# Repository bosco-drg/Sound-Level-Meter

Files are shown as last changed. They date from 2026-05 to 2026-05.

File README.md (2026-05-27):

# Sonomètre — Projet de mesure de niveau sonore

> Projet complet de sonomètre électronique : schéma, PCB (KiCad) et simulations (LTSpice).

---

## Aperçu rapide

Ce dépôt contient la conception d'un **sonomètre** (instrument de mesure du niveau sonore) couvrant l'adaptation d'entrée, la conditionnement du signal, le filtrage, la détection RMS/Crête, l'acquisition et les aspects matériels (schéma et PCB). Sont inclus : le **schéma**, le **PCB** et les **simulations**.

### Points clés

- **Mesure de niveau sonore** : détection RMS et/ou crête, calcul de niveaux (dB SPL)
- **Pondérations et filtres** : options de filtrage (pondération A/B) pour mesures conforme
- **Calibration** : procédures et composants pour calibration avec source connue
- **Conception matérielle** : schéma et routage PCB sous KiCad
- **Simulations** : modèles LTSpice pour valider le conditionnement et la détection
- **Documentation visuelle** : diagrammes fonctionnels et captures de simulation

---

## PCB

<div align="center">

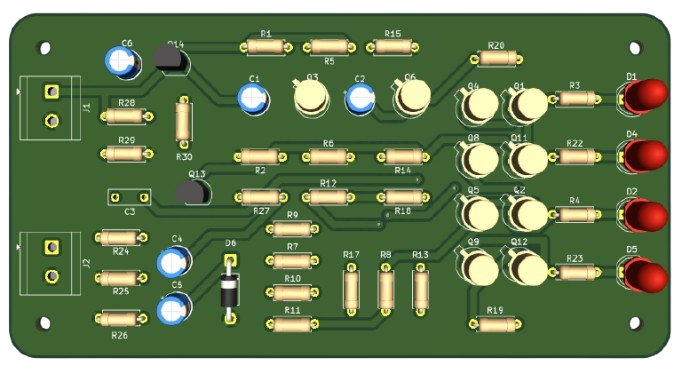
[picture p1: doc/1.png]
PCB back side


**PCB — côté composants**

</div>

<div align="center">

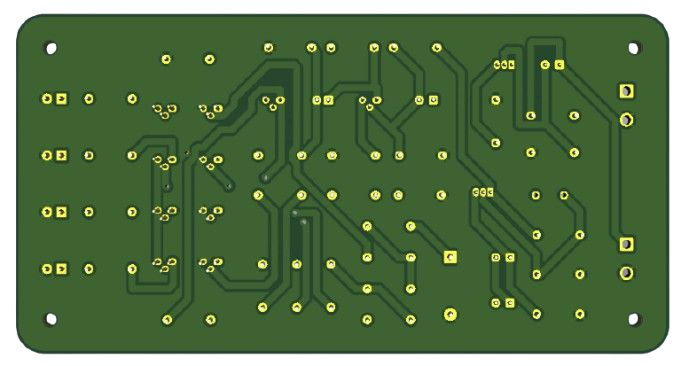
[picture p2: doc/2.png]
PCB component side


**PCB — verso**

</div>

---

## Structure du projet

```
Sound-Level-Meter/
├── README.md
├── doc/                       # Documentation visuelle et images
├── schematic_Kicad/           # Projet KiCad (schéma + PCB)
│   └── Projet2_EC/
│       ├── Projet2_EC.kicad_sch
│       ├── Projet2_EC.kicad_pcb
│       └── fp-info-cache/
└── simulation/
	└── sound_level_meter_SPICE.asc
```

---

## Ouvrir le projet

### KiCad
- Ouvrir le projet dans [schematic_Kicad/Projet2_EC/](schematic_Kicad/Projet2_EC/)
- Fichiers principaux :
	- Schéma : [schematic_Kicad/Projet2_EC/Projet2_EC.kicad_sch](schematic_Kicad/Projet2_EC/Projet2_EC.kicad_sch)
	- PCB : [schematic_Kicad/Projet2_EC/Projet2_EC.kicad_pcb](schematic_Kicad/Projet2_EC/Projet2_EC.kicad_pcb)

### LTSpice
- Schéma de simulation : [simulation/sound_level_meter_SPICE.asc](simulation/sound_level_meter_SPICE.asc)

---

## Auteurs

- **Bosco de Rauglaudre**
- **Titouan Bocquet**
- **Gavin Mac Aonghusa**

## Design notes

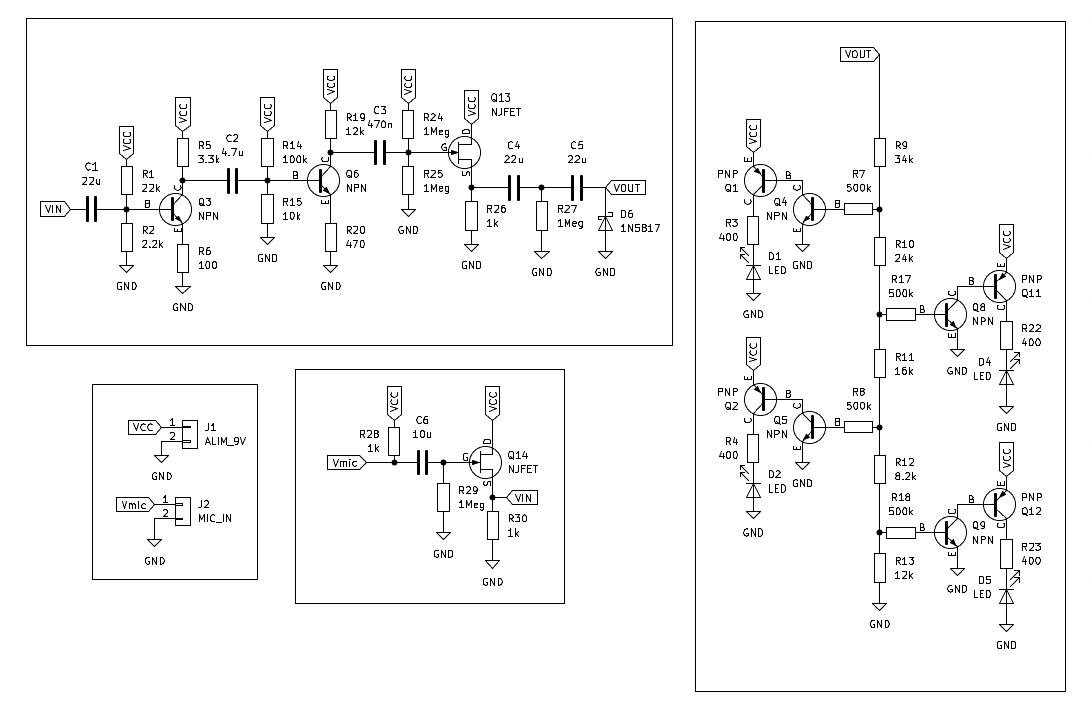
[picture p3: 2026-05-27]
doc/Schematic.png

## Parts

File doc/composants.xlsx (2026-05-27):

Complétez tous les champs
Composants disponibles en salle de TP : résistances et condensateurs standards, AOP LM741, indiquez seulement la valeur et la quantité souhaitée
Fournisseurs : Radiospares (https://fr.rs-online.com/web/) OU Farnell (fr.farnell.com)
Numéro de binôme : 3 |  | Groupe de TD : 1
Fournissseur | Dénomination | Référence | Code commande | Quantité | Stock restant
 | Résistance 100k |  |  | 5
 | Résistance 400 |  |  | 5
 | Résistance 3.3k |  |  | 3
 | Résistance 1.5k |  |  | 1
 | Résistance 820 |  |  | 1
 | Résistance 8.2k |  |  | 1
 | Résistance 82k |  |  | 1
 | Résistance 1k |  |  | 4
 | Résistance 1Meg |  |  | 3
 | Résistance 130k |  |  | 1
 | Résistance 6.8k |  |  | 1
 | Résistance 2k |  |  | 1
 | Résistance 10k |  |  | 2
 | Résistance 20k |  |  | 2
 | Potentiomètre 1k |  |  | 1
 | Condensateur 22uF |  |  | 4
 | Condensateur 10uF |  |  | 1
RS | Schotky Diode 1N5817 | Redresseur Schottky STMicroelectronics Diode Schottky Simple, 20 V, , 1 A Traversant 2 broches DO-41 | 189-4375 | 50 | 550
RS | LED Rouge | LED, Kingbright 2 broches, Traversant Rouge 625 nm, 5 V 60 ° L53, 5 mm (T-1 3/4) | 228-5562 | 5 | .
RS | LED Jaune | LED, Kingbright 2 broches, Traversant Jaune 588 nm, 2.1 V 60 ° L53, 5 mm | 228-6010 | 5 | .
RS | LED Verte | LED, Kingbright 2 broches, Traversant Vert 568 nm, 2 V 60 ° L53, 5 mm (T-1 3/4) | 228-6004 | 5 | .
RS | Transistor 2N2907 | Transistor onsemi, -800 mA PnP, -60 V, 3 broches, TO-92 Simple | 739-0492 | 10 | 500
RS | Transistor 2N2222 | Transistor onsemi, 1 A NPN, 40 V, 3 broches, TO-92 Simple | 739-0381 | 15 | 920
RS | Transistor J113 | JFET onsemiCanal-Type N, Canal-JFET, Simple 2 mA, 3 broches TO-92 | 806-1766 | 5 | 100
RS | Connecteur de batterie 9V | Contact de batterie Goujon pression 9 V RS PRO | 185-4788 | 1 | 754
RS | Connecteur à vis | Bloc de jonction CI série CTB0509 3 contacts RS PRO Vertical pas de 5.08 mm Traversant 1 rangée(s) | 146-8346 | 4 | 130

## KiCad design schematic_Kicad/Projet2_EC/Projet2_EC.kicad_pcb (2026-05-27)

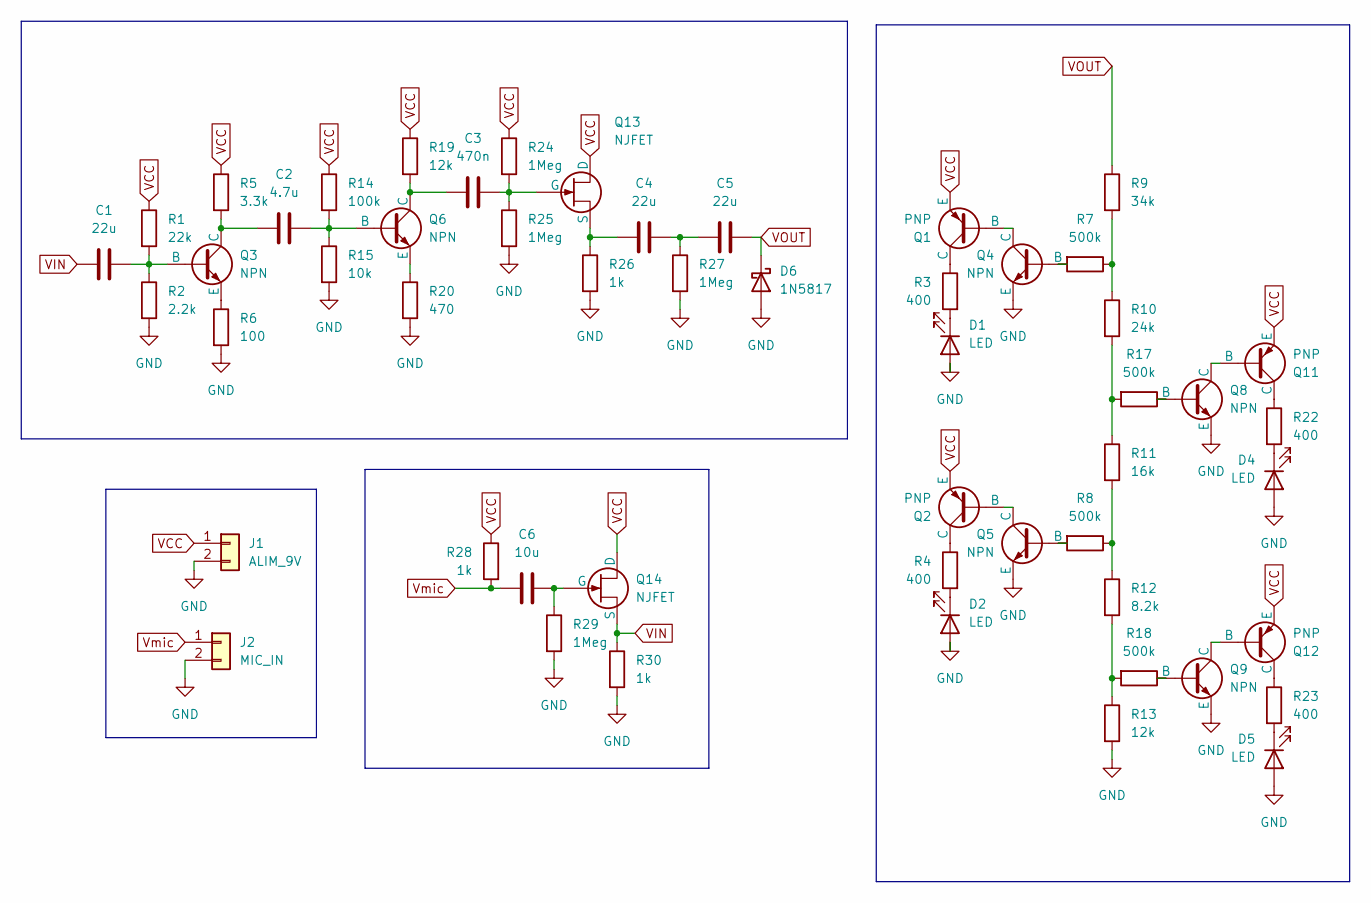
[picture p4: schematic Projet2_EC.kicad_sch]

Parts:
C1, C4, C5: 22u; CP_Radial_D5.0mm_P2.50mm
C2: 4.7u; CP_Radial_D5.0mm_P2.00mm
C3: 470n; C_Rect_L7.2mm_W2.5mm_P5.00mm
C6: 10u; CP_Radial_D5.0mm_P2.50mm
D1, D2, D4, D5: LED; LED_D5.0mm
D6: 1N5817; D_DO-41_SOD81_P10.16mm_Horizontal
J1: ALIM_9V; TerminalBlock_CUI_TB007-508-02_1x02_P5.08mm_Horizontal
J2: MIC_IN; TerminalBlock_CUI_TB007-508-02_1x02_P5.08mm_Horizontal
Q1, Q2, Q11, Q12: PNP; TO-18-3
Q3, Q4, Q5, Q6, Q8, Q9: NPN; TO-18-3
Q13, Q14: NJFET; TO-92_Inline
R1: 22k; R_Axial_DIN0207_L6.3mm_D2.5mm_P7.62mm_Horizontal
R2: 2.2k; R_Axial_DIN0207_L6.3mm_D2.5mm_P7.62mm_Horizontal
R3, R4, R22, R23: 400; R_Axial_DIN0207_L6.3mm_D2.5mm_P7.62mm_Horizontal
R5: 3.3k; R_Axial_DIN0207_L6.3mm_D2.5mm_P7.62mm_Horizontal
R6: 100; R_Axial_DIN0207_L6.3mm_D2.5mm_P7.62mm_Horizontal
R7, R8, R17, R18: 500k; R_Axial_DIN0207_L6.3mm_D2.5mm_P7.62mm_Horizontal
R9: 34k; R_Axial_DIN0207_L6.3mm_D2.5mm_P7.62mm_Horizontal
R10: 24k; R_Axial_DIN0207_L6.3mm_D2.5mm_P7.62mm_Horizontal
R11: 16k; R_Axial_DIN0207_L6.3mm_D2.5mm_P7.62mm_Horizontal
R12: 8.2k; R_Axial_DIN0207_L6.3mm_D2.5mm_P7.62mm_Horizontal
R13, R19: 12k; R_Axial_DIN0207_L6.3mm_D2.5mm_P7.62mm_Horizontal
R14: 100k; R_Axial_DIN0207_L6.3mm_D2.5mm_P7.62mm_Horizontal
R15: 10k; R_Axial_DIN0207_L6.3mm_D2.5mm_P7.62mm_Horizontal
R20: 470; R_Axial_DIN0207_L6.3mm_D2.5mm_P7.62mm_Horizontal
R24, R25, R27, R29: 1Meg; R_Axial_DIN0207_L6.3mm_D2.5mm_P7.62mm_Horizontal
R26, R28, R30: 1k; R_Axial_DIN0207_L6.3mm_D2.5mm_P7.62mm_Horizontal

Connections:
GND: D1.2 (A), D2.2 (A), D4.2 (A), D5.2 (A), D6.2 (A), J1.2, J2.2, Q4.3 (E), Q5.3 (E), Q8.3 (E), Q9.3 (E), R2.2, R6.2, R13.2, R15.2, R20.2, R25.2, R26.2, R27.2, R29.2, R30.2
unnamed: C4.2, C5.1, R27.1
unnamed: D1.1 (K), R3.2
unnamed: D2.1 (K), R4.2
unnamed: D4.1 (K), R22.2
unnamed: D5.1 (K), R23.2
unnamed: Q1.2 (B), Q4.1 (C)
unnamed: Q1.1 (C), R3.1
unnamed: Q2.2 (B), Q5.1 (C)
unnamed: Q2.1 (C), R4.1
unnamed: C1.2, Q3.2 (B), R1.2, R2.1
unnamed: C2.1, Q3.1 (C), R5.2
unnamed: Q3.3 (E), R6.1
unnamed: Q4.2 (B), R7.2
unnamed: Q5.2 (B), R8.2
unnamed: C2.2, Q6.2 (B), R14.2, R15.1
unnamed: C3.1, Q6.1 (C), R19.2
unnamed: Q6.3 (E), R20.1
unnamed: Q8.2 (B), R17.1
unnamed: Q9.2 (B), R18.1
unnamed: Q8.1 (C), Q11.2 (B)
unnamed: Q11.1 (C), R22.1
unnamed: Q9.1 (C), Q12.2 (B)
unnamed: Q12.1 (C), R23.1
unnamed: C3.2, Q13.2 (G), R24.2, R25.1
unnamed: C4.1, Q13.3 (S), R26.1
unnamed: C6.2, Q14.2 (G), R29.1
unnamed: R7.1, R9.2, R10.1
unnamed: R10.2, R11.1, R17.2
unnamed: R8.1, R11.2, R12.1
unnamed: R12.2, R13.1, R18.2
VCC: J1.1, Q1.3 (E), Q2.3 (E), Q11.3 (E), Q12.3 (E), Q13.1 (D), Q14.1 (D), R1.1, R5.1, R14.1, R19.1, R24.1, R28.1
VIN: C1.1, Q14.3 (S), R30.1
VOUT: C5.2, D6.1 (K), R9.1
Vmic: C6.1, J2.1, R28.2

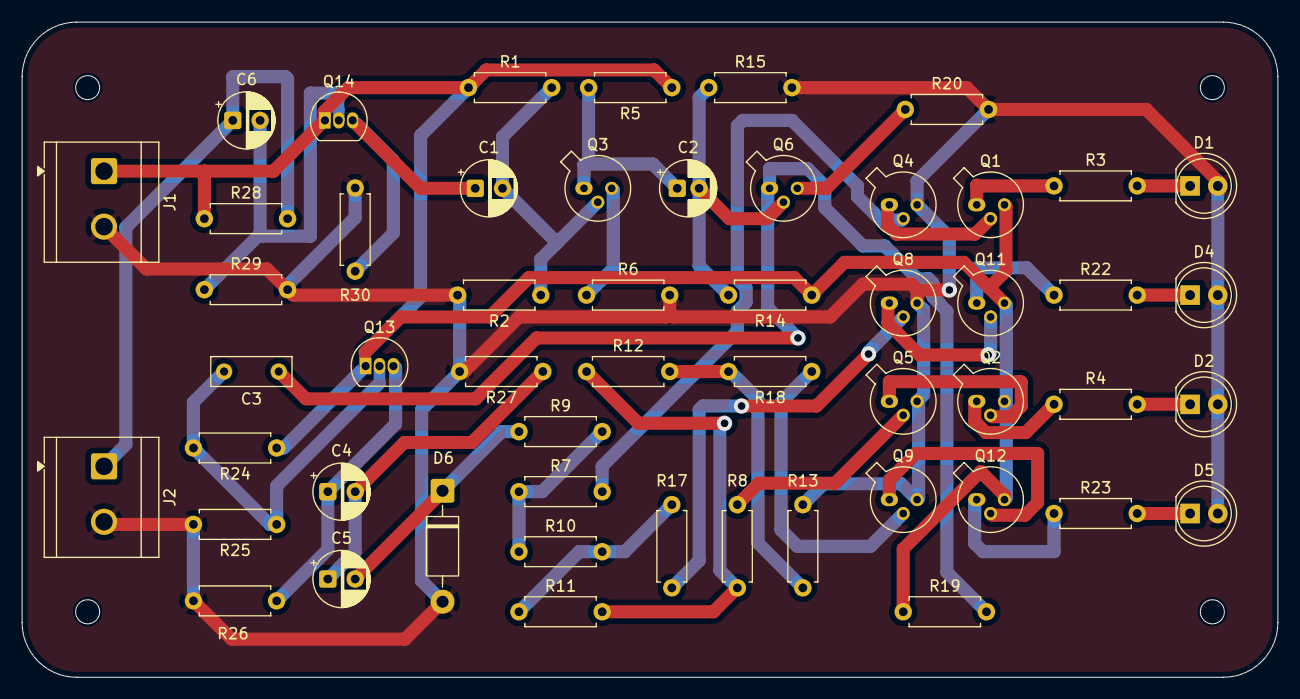
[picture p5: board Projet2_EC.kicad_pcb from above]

Board: 2 copper layers, 115.0 x 60.0 mm, 53 parts (0 on the bottom side), 35 nets.

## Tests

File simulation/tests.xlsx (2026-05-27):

 | Avec les condensateurs sans charges
 | Input Impedance |  |  |  |  |  | output Impedance
 | Théorique | Simulé | pratique |  |  |  | Théorique | Simulé | pratique
J1 | 1M | 900k |  |  |  | J1 | 135 | 134
Amp1 | 1900 | 1.8k | 1150 |  |  | Amp1 | 4300 | 4.6k
Amp2 | 8366 | 8.4k |  |  |  | Amp2 | 10900 | 11.8k
J2 | 500k | 500k |  |  |  | J2 | 67 | 140 | 132
 | entrée | sortie de villard | Gain | fréquence | dB |  | sortie avant villard | Gain | dB
 | 0.02 | 5.66 | 283 | 20 | 49.03572871 |  | 5.42 | 271 | 48.65938582
 | 0.02 | 6.16 | 308 | 32 | 49.77101433 |  | 5.94 | 297 | 49.45512899
 | 0.02 | 6.54 | 327 | 53 | 50.29095505 |  | 6.31 | 315.5 | 49.97998727
 | 0.02 | 6.53 | 326.5 | 87 | 50.27766371 |  | 6.33 | 316.5 | 50.00747429
 | 0.02 | 6.17 | 308.5 | 143 | 49.78510337 |  | 6.07 | 303.5 | 49.64317391
 | 0.02 | 6 | 300 | 235 | 49.54242509 |  | 5.88 | 294 | 49.36694661
 | 0.0198 | 5.93 | 299.4949495 | 385 | 49.52779006 |  | 5.69 | 287.3737374 | 49.16894152
 | 0.02 | 5.89 | 294.5 | 630 | 49.38170598 |  | 5.81 | 290.5 | 49.26292273
 | 0.0198 | 5.87 | 296.4646465 | 1000 | 49.43945822 |  | 5.82 | 293.9393939 | 49.36515589
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
